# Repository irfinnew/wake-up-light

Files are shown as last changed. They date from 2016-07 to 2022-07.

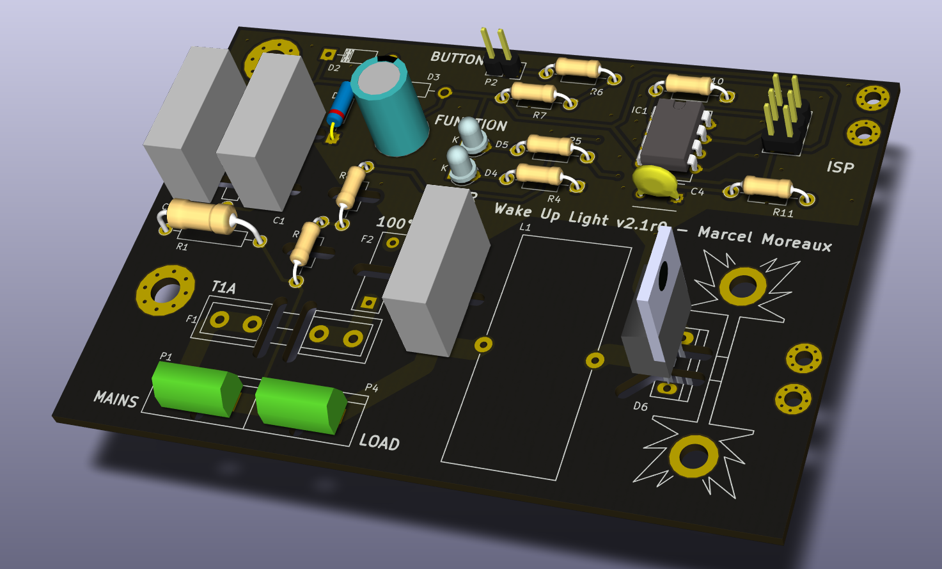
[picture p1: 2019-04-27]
pcb/render_parts.png

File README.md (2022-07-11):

Wake-Up Light cover image

# About

This is a dawn simulation lamp I made for my personal use.

A dawn simulator wakes you up by simulating sunrise in the bedroom; the increasing amount of light starts preparing your body for awakening.
The end result is that you naturally wake up on your own, instead of being jarred awake by the usual alarm clock sounds.

When it receives power, the wake-up light

 - Very gently increases from darkness to full brightness over the course of 30 minutes,
 - Remains at full brightness for 45 minutes,
 - Then turns off fairly quickly.

The wake-up light is switched on by a plug-in timer that activates 45 minutes before my intended rise time.

It also includes a button to toggle the light between off and full brightness, so I can turn it off after I get up.

# Design

The light controller is a classic [phase-cutting](https://en.wikipedia.org/wiki/Phase-fired_controller) triac dimmer, with zero-cross detection and triac control performed by a small microcontroller.
The dimmer drives a 150W halogen floodlight, which gives a nice orange glow at low brightness, but provides reasonably white full-spectrum light at high brightness.

The design was also a bit of an engineering exercise; I wanted to end up with a fairly minimal design without compromising stability or reliability.

## Isolation

The controller is not isolated from mains; it uses a capacitive dropper power supply, and the MCU is connected directly to the triac.
As a result, the entire circuit may be at mains potential, it must be installed so that users can't touch any of it.
This also applies to the button, which must provide adequate isolation.

The MCU also connects directly to mains for zero-cross sensing, as inspired by [Atmel application note AN2508](https://ww1.microchip.com/downloads/en/Appnotes/Atmel-2508-Zero-Cross-Detector_ApplicationNote_AVR182.pdf).

## Mains voltage and frequency

The controller was designed to run on 230VAC @ 50Hz.
If you want to run it on 120VAC, the power supply caps (`C1/C2`) probably should be doubled in value.
The firmware should be able to deal with 60Hz without problems, but I haven't tested this.

# Sources

The PCB layout is provided as a [KiCad](https://www.kicad.org/) project in `pcb/`.
The project uses a handful of custom footprints in `pcb/WakeUpLight.pretty/`, you'll need to import them into KiCad.

Gerber files in `pcb/gerber/`.

## Firmware

The firmware for the ATTiny45P lives in `mcu/`.
It is written in C, for `avr-gcc` / `avr-libc`.
If you have a `stk500v1` compatible programmer on USB and `avrdude`, just `SERIAL=/dev/ttyUSB0 make upload` should do the trick.

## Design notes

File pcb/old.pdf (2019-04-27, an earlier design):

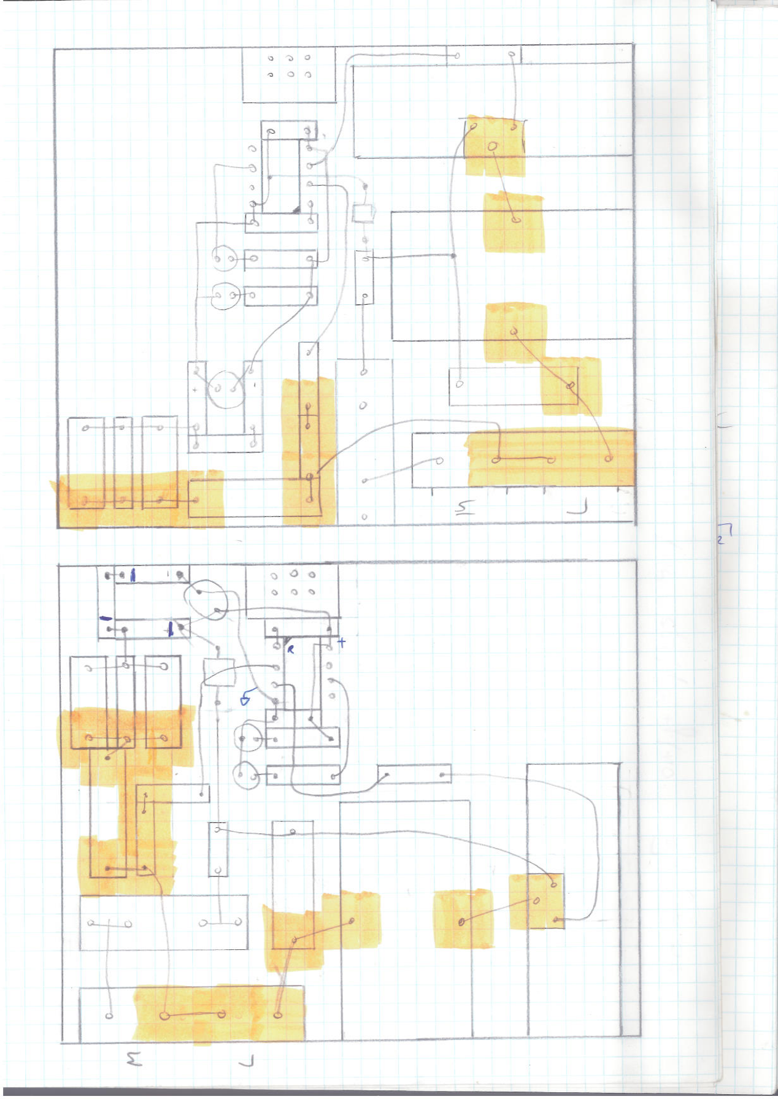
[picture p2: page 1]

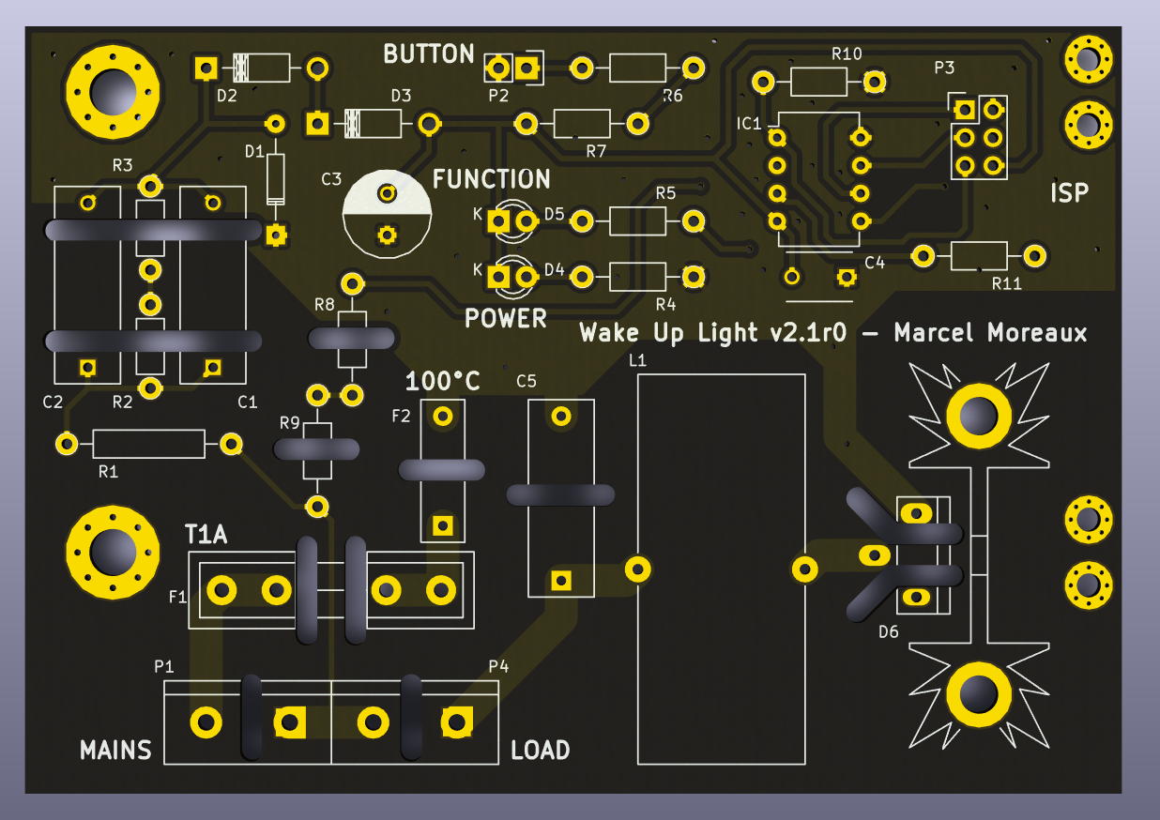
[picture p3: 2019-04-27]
pcb/render_front.png

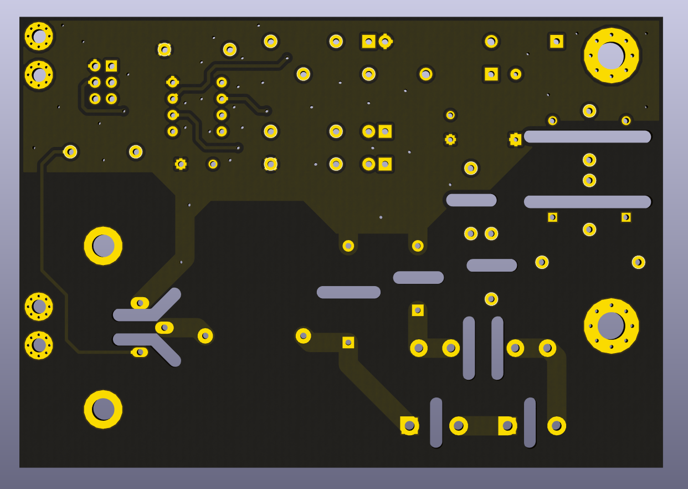
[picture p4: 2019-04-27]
pcb/render_back.png

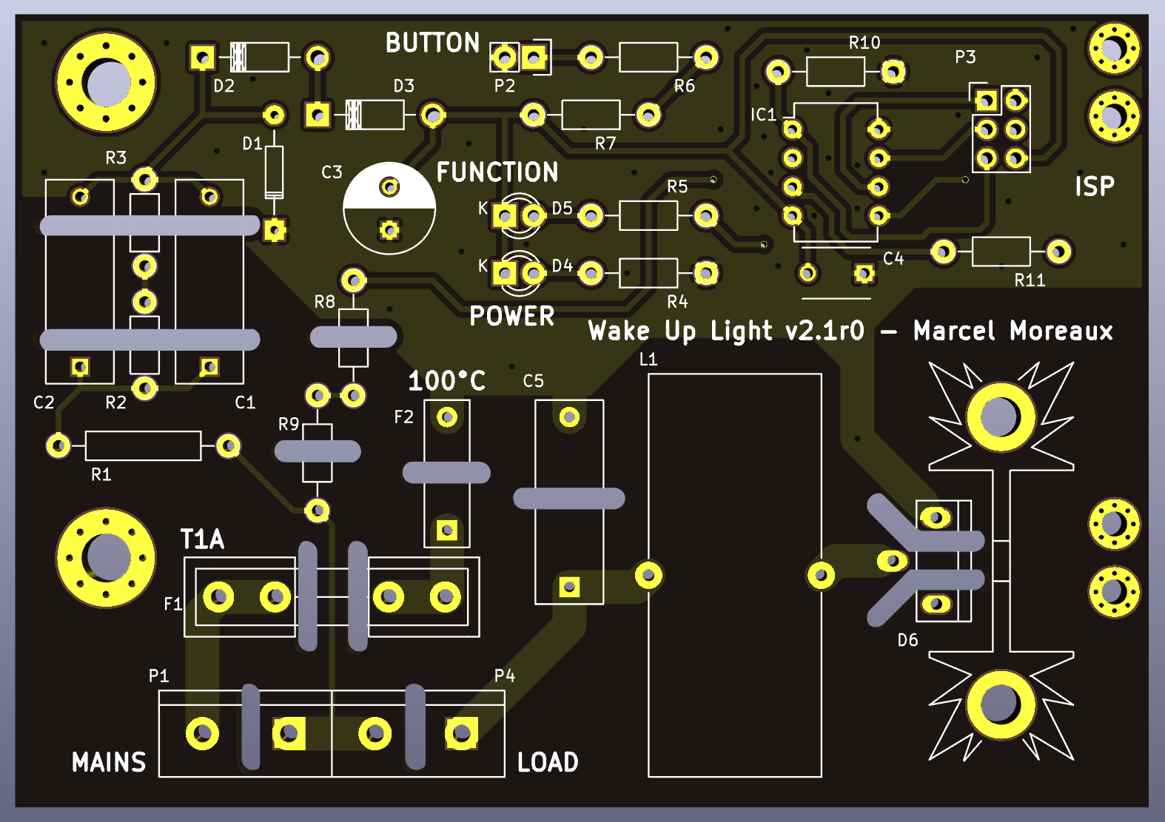
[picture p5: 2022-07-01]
pcb/render_front2.png

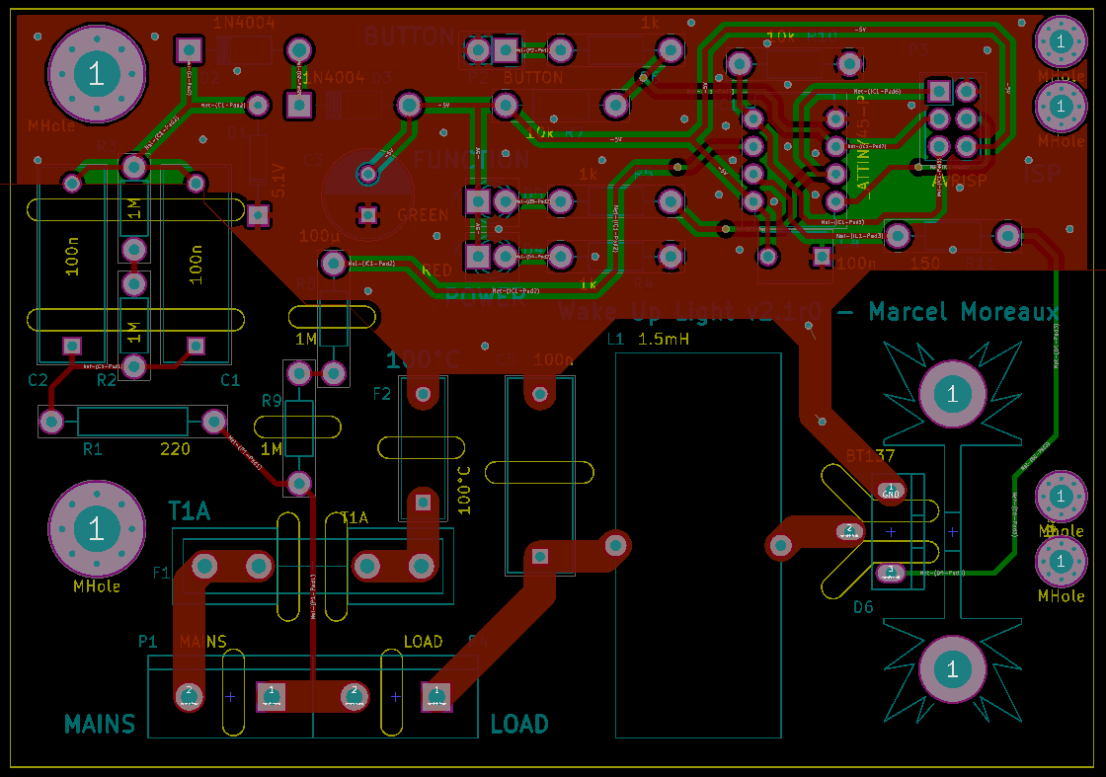
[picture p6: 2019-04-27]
pcb/layout.png

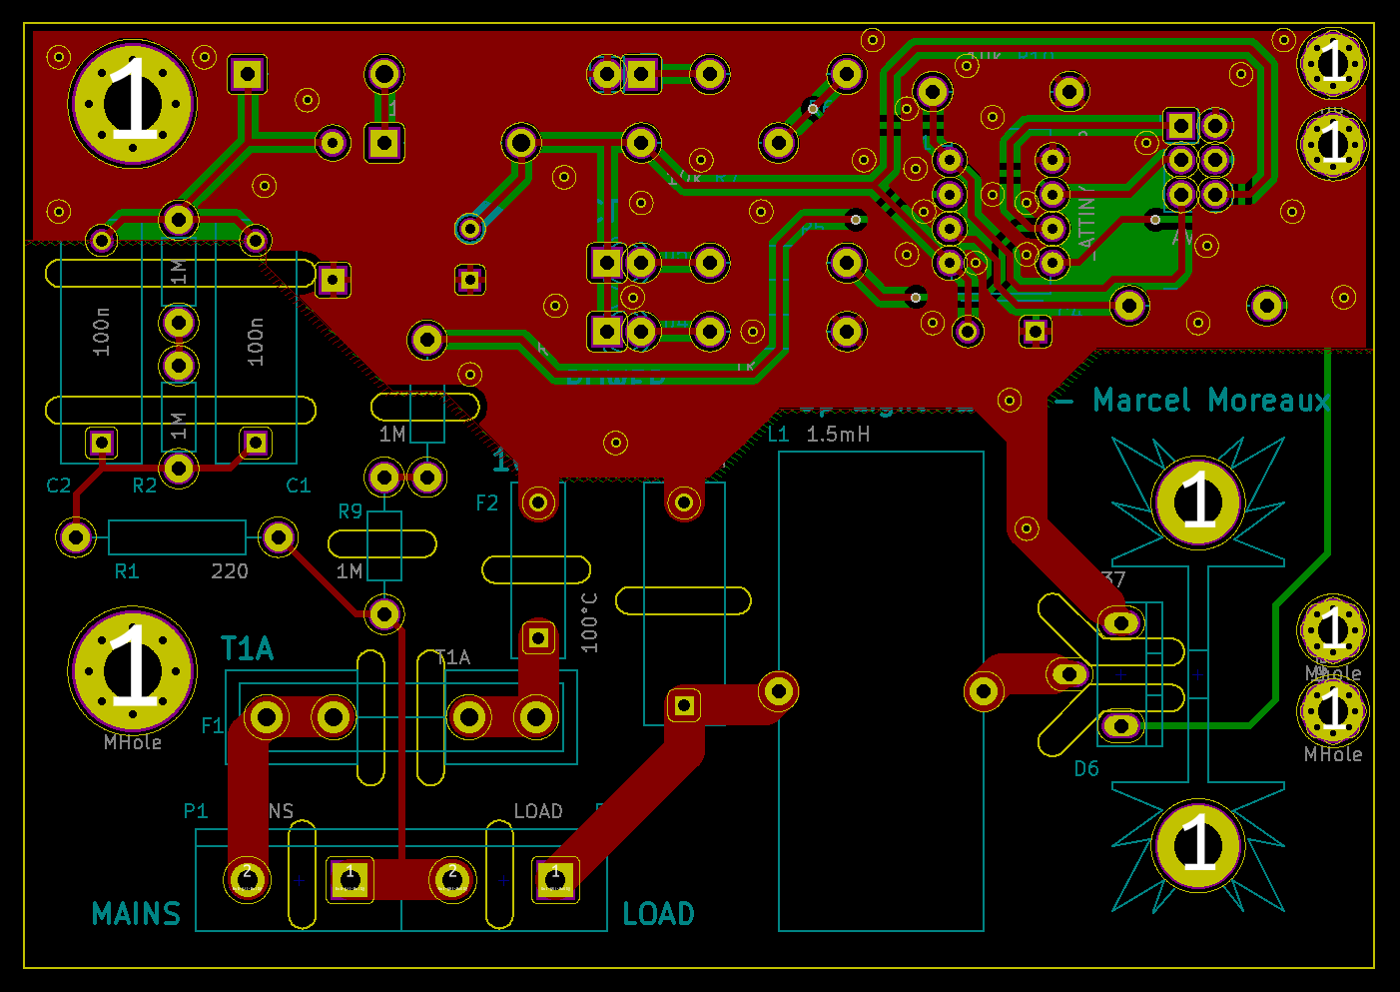
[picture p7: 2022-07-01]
pcb/layout2.png

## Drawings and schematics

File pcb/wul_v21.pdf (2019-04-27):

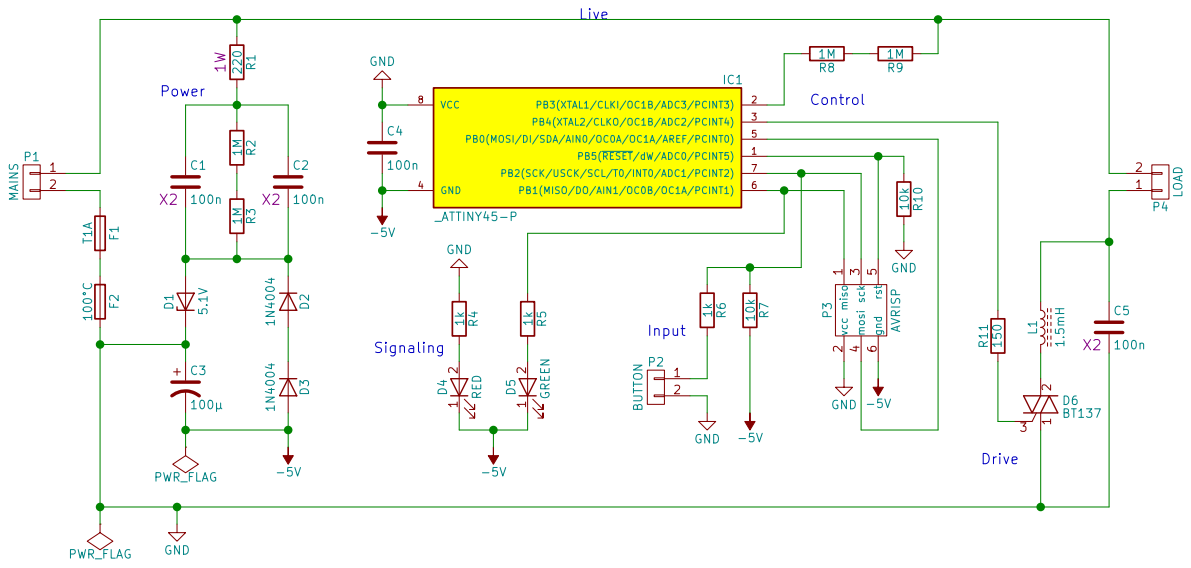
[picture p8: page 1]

Leading-edge phase cutting triac dimmer
File: wul_v21.sch Sheet: / Marcel Moreaux

Id: 1/1 Title: Wake Up Light v2.1

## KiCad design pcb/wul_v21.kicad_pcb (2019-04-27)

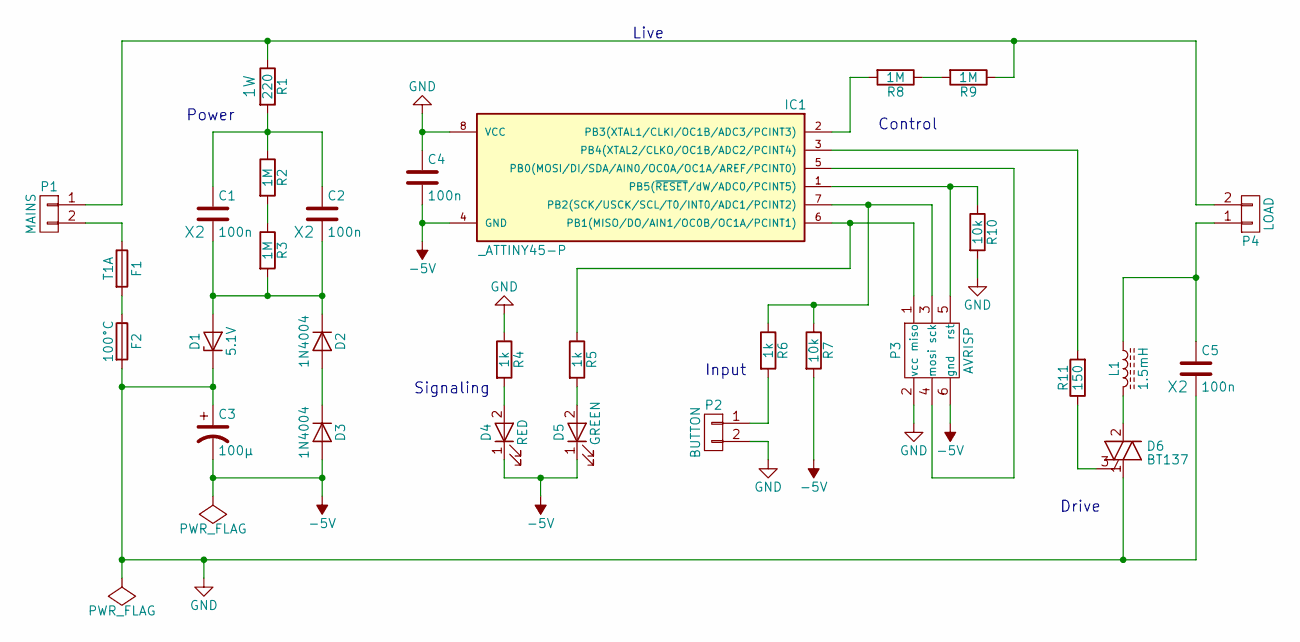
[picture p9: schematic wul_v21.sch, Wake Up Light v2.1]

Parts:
C1, C2, C5: 100n; C_Rect_L18_W6_H12_P15; Rating X2
C3: 100µ; C_Radial_D8_L13_P3.8
C4: 100n; C_Disc_D6_P5
D1: 5.1V; Diode_DO-35_SOD27_Horizontal_RM10
D2, D3: 1N4004; Diode_DO-41_SOD81_Horizontal_RM10
D4: RED; LED-3MM
D5: GREEN; LED-3MM
D6: BT137; TO-220_Wide
F1: T1A; Fuseholder5x20_horiz_open_inline_Type-I
F2: 100°C; C_Rect_L13_W4_P10
IC1: _ATTINY45-P; DIP-8_W7.62mm
L1: 1.5mH; Choke_Toroid_15x36mm_Vertical
P1: MAINS; bornier2_wide
P2: BUTTON; Pin_Header_Straight_1x02
P3: AVRISP; Pin_Header_Straight_2x03
P4: LOAD; bornier2_wide
R1: 220; Resistor_Horizontal_RM15mm; Rating 1W
R2, R3: 1M; Resistor_Horizontal_RM7mm
R4, R5, R6: 1k; Resistor_Horizontal_RM10mm
R7, R10: 10k; Resistor_Horizontal_RM10mm
R8, R9: 1M; Resistor_Horizontal_RM10mm
R11: 150; Resistor_Horizontal_RM10mm

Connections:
-5V: C3.2, C4.2, D3.2 (A), D4.1 (K), D5.1 (K), IC1.4 (GND), P3.6 (gnd), R7.2
GND: C3.1, C4.1, C5.2, D1.1 (K), D6.1 (A2), F2.2, IC1.8 (VCC), P2.2, P3.2 (vcc), R4.1, R10.2
unnamed: C1.1, C2.1, R1.2, R2.1
unnamed: C1.2, C2.2, D1.2 (A), D2.1 (K), R3.2
unnamed: C5.1, L1.1, P4.1
unnamed: D2.2 (A), D3.1 (K)
unnamed: D4.2 (A), R4.2
unnamed: D5.2 (A), R5.2
unnamed: D6.2 (A1), L1.2
unnamed: D6.3 (G), R11.1
unnamed: F1.1, P1.2
unnamed: F1.2, F2.1
unnamed: IC1.1 (PB5(~RESET~/dW/ADC0/PCINT5)), P3.5 (rst), R10.1
unnamed: IC1.2 (PB3(XTAL1/CLKI/OC1B/ADC3/PCINT3)), R8.2
unnamed: IC1.3 (PB4(XTAL2/CLKO/OC1B/ADC2/PCINT4)), R11.2
unnamed: IC1.5 (PB0(MOSI/DI/SDA/AIN0/OC0A/OC1A/AREF/PCI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), P3.4 (mosi)
unnamed: IC1.6 (PB1(MISO/DO/AIN1/OC0B/OC1A/PCINT1)), P3.1 (miso), R5.1
unnamed: IC1.7 (PB2(SCK/USCK/SCL/T0/INT0/ADC1/PCINT2)), P3.3 (sck), R6.1, R7.1
unnamed: P1.1, P4.2, R1.1, R9.1
unnamed: P2.1, R6.2
unnamed: R2.2, R3.1
unnamed: R8.1, R9.2

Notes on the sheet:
Power
Drive
Signaling
Input
Control
Live

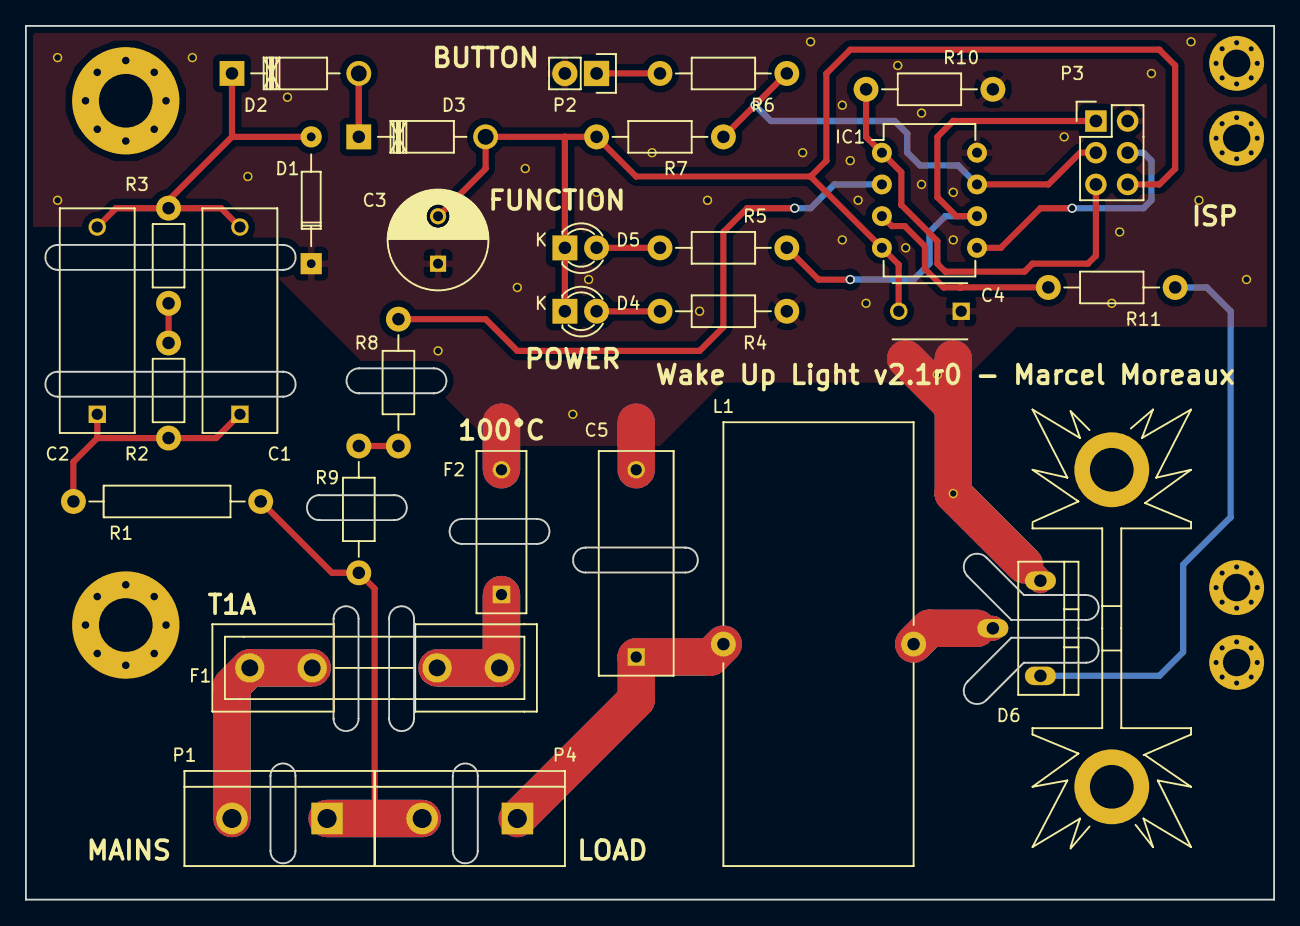
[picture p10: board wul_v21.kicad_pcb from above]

Board: 2 copper layers, 100.0 x 70.0 mm, 30 parts (0 on the bottom side), 22 nets.

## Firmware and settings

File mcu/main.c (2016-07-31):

#define F_CPU (2*1000000UL)

#include <avr/io.h>
#include <util/delay.h>

#define US_PULSE 100
#define LVL_MAX 0x7fffffff
#define LVL_SCALE(x) (((x) >> 16) << 1)
#define LVL_RAMP(x) (LVL_MAX / 100 / (x))

#define PIN_ZEROCROSS PB3
#define PIN_LED       PB1
#define PIN_BUTTON    PB2
#define PIN_TRIAC     PB4



// Fast 16x16 -> high16 multiplication approximation.
// Equivalent to (a * b) >> 16  (ignoring overflow)
//
// XXX: this function is an approximation. In 25% of the cases, the 
// return value is 1 lower than it should be. Never higher.
//
// Cycle count on GCC 4.8.1 with -Os: 166 + (# of bits set in <a>)
// (add 7 for call/ret)
unsigned int mul16_h16(unsigned int a, unsigned int b)
{
	unsigned int c = 0;
	unsigned char i;

	b >>= 1;
	for (i = 0; i < 16; i++)
	{
		c >>= 1;
		if (a & 0x01)
			c += b;
		a >>= 1;
	}
	return c;
}



// Blinks the led. Call once every semicycle. The parameters indicate
// how many semicycles the led should be on, and how many off (254 MAX).
// E.g. blink(50, 50) is 0.5 sec on, 0.5 sec off (assuming 50Hz)
// blink(10, 90) is 0.1 sec on, 0.9 off. etc.
void blink(unsigned char on, unsigned char off)
{
	static unsigned char state = 0;
	static unsigned char count = 0;

	count++;

	if (state == 0 && count > off && on > 0)
	{
		PORTB |= _BV(PIN_LED);
		state = 1;
		count = 0;
		return;
	}

	if (state == 1 && count > on && off > 0)
	{
		PORTB &= ~_BV(PIN_LED);
		state = 0;
		count = 0;
		return;
	}
}



// Returns true iff the button is pressed and was depressed the previous 7
// invocations of this function. If polled every semicycle, this provides
// good debouncing.
unsigned char button_pressed(void)
{
	static unsigned char acc = 0;

	acc <<= 1;
	if (PINB & _BV(PIN_BUTTON))
		acc |= 1;

	return acc == 0x01;
}



// They "main loop" function, which waits out the rest of the semicycle,
// triggering the triac at an appropriate moment (as indicated by level).
// Call this function, do a little processing, call it again, etc, etc.
// Try to keep time between calls as constant as possible.
// Level indicates brightness, ranging from 0 to 0xffff.
// Actual resolution appears to be something like 1 in 1500.
void cycle(unsigned int level)
{
	// Keep track of which semicycle we're dealing with.
	// 0xff for the lower semicycle, 0x00 for the upper half.
	static unsigned char which = 0x00;
	// The mains cycle length in loop counts. About 1500-ish.
	static unsigned int cycle_len = 0xffff;
	// Loop counter for the current iteration.
	unsigned int count = 0;
	// Target loop counts after which to trigger the triac.
	unsigned int target = 0;



	// Implement a level scaling that starts out linear but
	// tends to hypercubed eventually. This is a lot closer to
	// perceived linear brightness due to the way incandescents
	// and AC sine waves interact. (abuses <target> as temp var)
	target = mul16_h16(level, level);
	target = mul16_h16(target, target);
	target = (target >> 1) + (level >> 1);

	// Invert level; a low level translates to a high target
	target = 0xffffU - target;
	// We pretend the cycle is shorter than it really is, to prevent
	// overshoot. About 0x40 seems really needed to prevent incorrect triac
	// triggering. The larger value makes level=0 close to the glow point
	// of the halogens I use.
	target = mul16_h16(cycle_len - 0x90, target);

	// At lowest level, set an unreachable target to ensure the triac
	// never gets fired. (count seems to run up to 1500-ish)
	// The expensive target calculation is discarded in this case, but we
	// want the computations to always happen to avoid runtime variations.
	if (level == 0)
		target = 0xffffU;



	// Because of the way this zero-cross detection works, the upper
	// semicycle appears longer by about 1%.  We compensate for this by
	// delaying for a bit before the main loop of the lower semicycle.
	// This ensures <count> is roughly the same for both semis.
	// 63us empirically found to be most stable.
	if (!which)
		_delay_us(63);



	count = 0;
	// Bitwise I/O accumulator, for debouncing.
	unsigned char io_acc = ~which;
	// Copy of <which> in a non-static variable. Otherwise GCC fails to
	// realize it doesn't have to fetch <which> from SRAM every iteration.
	unsigned char io_tgt = which;
	// Actual phase timing loop starts here.
	while (io_acc != io_tgt)
	{
		io_acc <<= 1;
		if (PINB & _BV(PIN_ZEROCROSS))
			io_acc |= 1;

		if (count == target)
		{
			PORTB &= ~_BV(PIN_TRIAC);
			_delay_us(US_PULSE);
			PORTB |= _BV(PIN_TRIAC);
			// Count compensation because of pulse delay.
			// One count should be 13 cycles.
			// One pulse is 100us, or 200 cycles at 2 MHz.
			// So, compensate by 200 / 13 = 15.
			count += 15;
		}

		count++;
	}

	// Start-up hack.
	// <cycle_len> starts out at 0xffff. <count> will be 1500-ish, so
	// <cycle_len> gets decreased each iteration. After 4 iterations,
	// it reaches 0xfffb, triggering a one-time shortcut to <count>.
	if (cycle_len == 0xfffb)
		cycle_len = count;

	// Adjust cycle_len, if needed. Adjusting by one step max prevents
	// noise on the zero-cross detector from messing things up too badly.
	if (count > cycle_len)
		cycle_len++;
	if (count < cycle_len)
		cycle_len--;

	// Select the other semicycle.
	which = ~which;
}



int main (void)
{
	unsigned long level;

	// Set clock prescaler to 256, resulting in a ~32KHz clock.
	// This minimizes power consumption.
	CLKPR = 0x80;
	CLKPR = 0x08;

	// Wait a little. At minimal power consumption, this allows the power
	// supply to stabilize. At 1/64th clock, this actually delays ~64ms.
	_delay_ms(1);

	// Set clock prescaler to 4, resulting in a ~2MHz clock.
	// This is our actual working frequency.
	CLKPR = 0x80;
	CLKPR = 0x02;

	// Set outputs
	PORTB |= _BV(PIN_TRIAC); // High = inactive
	DDRB = _BV(PIN_TRIAC) | _BV(PIN_LED);

	// Synchronize to the AC sine wave.
	cycle(0);
	cycle(0);



	// Ramp up
	for (level = 0; level <= LVL_MAX; level += LVL_RAMP(1800))
	{
		cycle(LVL_SCALE(level));
		blink(5, 15);
		if (button_pressed())
			goto off;
	}

	// Steady
	for (level = 0; level <= LVL_MAX; level += LVL_RAMP(2700))
	{
		cycle(0xffffU);
		blink(1, 0);
		if (button_pressed())
		{
			level = LVL_MAX;
			goto off;
		}
	}

	// Ramp down
	for (level = LVL_MAX; level <= LVL_MAX; level -= LVL_RAMP(2))
	{
		cycle(LVL_SCALE(level));
		blink(15, 5);
	}

off:
	// Off
	for (; level <= LVL_MAX; level -= LVL_RAMP(0.5))
	{
		cycle(LVL_SCALE(level));
		blink(5, 5);
		if (button_pressed())
			goto on;
	}
	level = 0;
	for (;;)
	{
		cycle(0);
		blink(5, 95);
		if (button_pressed())
			goto on;
	}

on:
	// On (only reachable by button)
	for (; level <= LVL_MAX; level += LVL_RAMP(1))
	{
		cycle(LVL_SCALE(level));
		blink(5, 5);
		if (button_pressed())
			goto off;
	}
	level = LVL_MAX;
	for (;;)
	{
		cycle(0xffffU);
		blink(95, 5);
		if (button_pressed())
			goto off;
	}

}

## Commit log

2015-12-24 Added button support.
2015-12-24 Better button support.
2016-07-31 Macro fixes + comment improvements.
    [main.c]
2019-04-27 Added pcb/
    [wul_v21.kicad_pcb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]
